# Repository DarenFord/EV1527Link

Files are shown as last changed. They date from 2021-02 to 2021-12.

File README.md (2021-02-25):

# EV1527Link
An EV1527 gateway for use with Domoticz or other home automation systems that support RF Link protocol.

# Download
https://github.com/DarenFord/EV1527Link/releases/latest

# Description
I'm a long-time user of Domoticz and the RF Link gateway (http://www.rflink.nl/blog2/). This is a great combination and works for lots of different home automation products and protocols (like KAKU, X10 and many others). It does, however, not support the EV1527 protocol very well and communication with security products (like door/window sensors, garage door openers, motion sensors, remote controls, etc...) either doesn't work or is unreliable.

I wanted to use cheap security products in my home automation system (like the Kerui D026 door/window sensor, which didn't work correctly/reliably with RF Link) and this led to creating a new gateway specifically for security products that use the EV1527 protocol. The gateway uses RF Link serial protocol to communicate with the home automation system as this protocol is already supported in Domoticz and some other home automation systems.

# Hardware
A Fritzing schematic diagram is included in the package and is extemely simple to wire-up. Build it on an experimental breadboard first to test that it works and, when you're happy, solder the components onto a prototype PCB. If you're feeling really adventurous, you could create a PCB layout and contribute it to the project :-)

It is important to use a good quality receiver module. The receiver module that sometimes comes with the FS-1000A transmitter module is not good enough and I would suggest using an RXB6 module (see parts list below) or something of similar quality.

The parts required to build the gateway:
- 1x Arduino Nano (or other Arduino with a USB port)
- 1x A good 433MHz receiver and ASK transmitter module (e.g. RXB6 receiver and transmitter set https://www.aliexpress.com/item/1005001504888006.html)
- 2x 1K resistor
- 1x Red LED
- 1x Green LED
- 1x Push button for testing

# Installation
Open the .ino file in the repository in the Arduino IDE. Compile and upload the project to your Arduino board.

# Configuration in Domoticz
Go to the hardware section in Domoticz and add a new hardware device with the name "EV1527Link", type "RF Link Gateway USB" and select the gateway's serial/USB port.

If you press the test button, you should see a new device appear in the device section of Domoticz.

I personally use the local (test) button input for the doorbell.

# LAN version
It is possible to connect the gateway directly to the local network and access it from Domoticz. To do this, add a serial to TCP converter (e.g. https://www.aliexpress.com/item/32329316229.html), connected to the TX & RX pins of the Arduino. Don't forget to level-shift the 5 volt TX from the Arduino to the 3 volt RX pin of the serial converter module and add jumpers to your circuit board, so that the converter can be disconnected if and when you need to (re)program the Arduino.

# Contribute to EV1527Link
If you want to contribute: Just create a pull request with your bugfix, addition or anything else you think is valuable.

Something that would be useful is a PCB layout in a format that is supported by PCB manufacturers.

Thanks for your help!

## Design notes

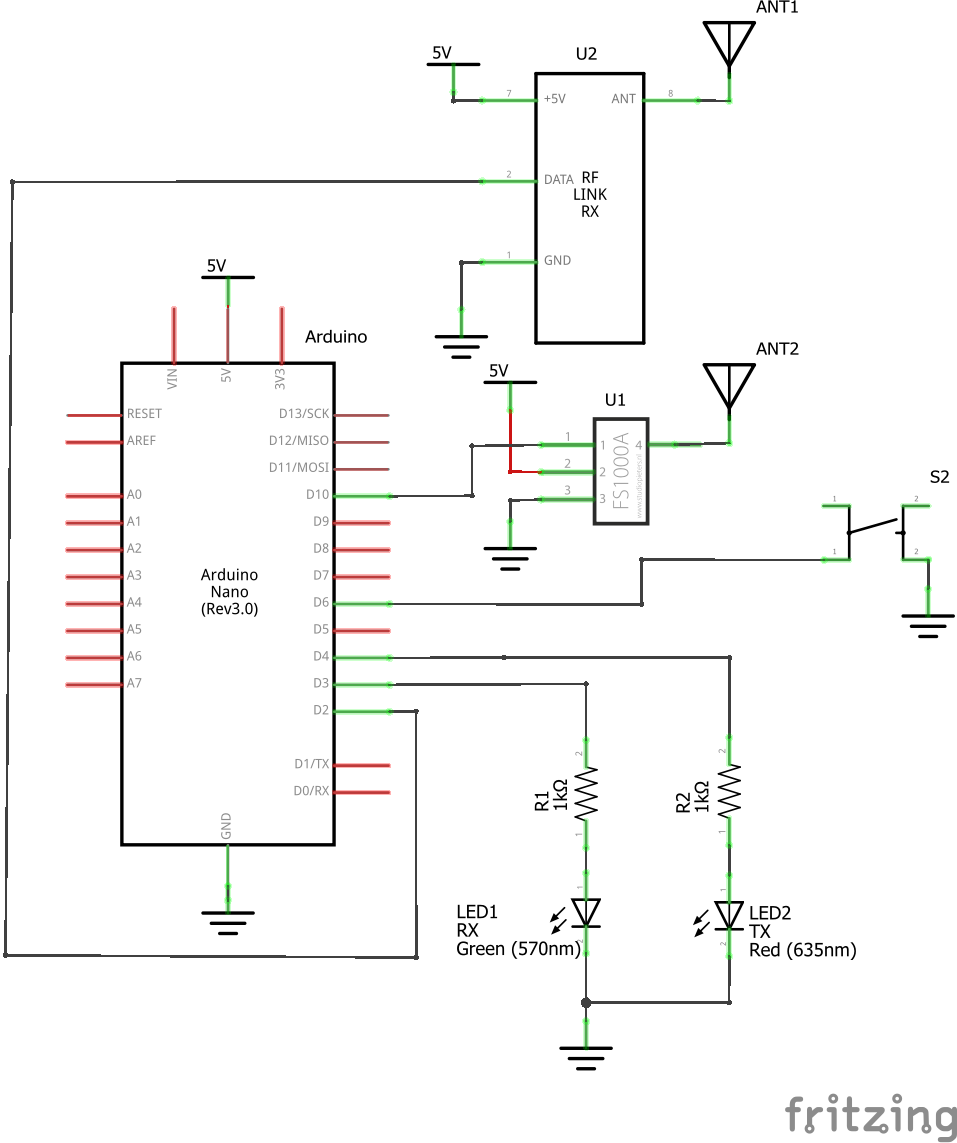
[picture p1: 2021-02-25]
schematic_schem.png

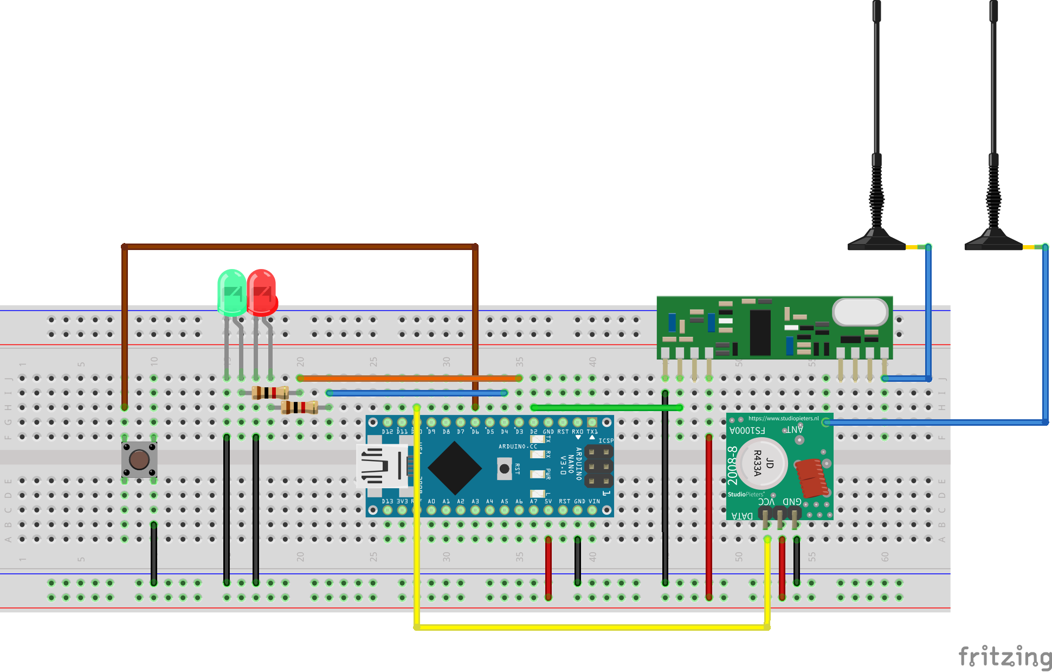
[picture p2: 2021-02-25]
schematic_bb.png

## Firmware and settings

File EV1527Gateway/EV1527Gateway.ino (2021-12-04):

/*
  An EV1527 gateway for use with domoticz and other home automation systems that use the RF Link serial protocol
  Copyright (c) 2020 Daren Ford.  All rights reserved.
    
  Last update: 26/09/2021
  Version: 2.0

  Changes: Added support for Byron protocol (doorbells) - watch out, they use alternating codes (so, two devices will be created)

  Example send command string: 10;Byron;295FD59;03;ON;

  Send commands:
  10;Byron;295FD59;3;ON;

  Loopback commands:
  11;20;45;EV1527;ID=295FD59;SWITCH=3;CMD=ON;
  11;20;45;Byron;ID=295FD59;SWITCH=3;CMD=ON;

  Loopback commands in Domoticz:
  20;45;EV1527;ID=295FD59;SWITCH=3;CMD=ON;
  20;45;Byron;ID=295FD59;SWITCH=3;CMD=ON;

  Project home: https://github.com/DarenFord/EV1527Link
  
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
  This software is distributed in the hope that it will be useful,
  but WITHOUT ANY WARRANTY; without even the implied warranty of
  MERCHANTABILITY or FITNESS FOR A PARTICULAR PURPOSE.  See the GNU
  Lesser General Public License for more details.
  You should have received a copy of the GNU Lesser General Public
  License along with this library; if not, write to the Free Software
  Foundation, Inc., 51 Franklin St, Fifth Floor, Boston, MA  02110-1301  USA  
*/

#include <RCSwitch.h>
#include <Bounce2.h>

//Format for protocol definitions:
//{pulselength, Sync bit, "0" bit, "1" bit}
RCSwitch::Protocol EV1527Protocol = {250, {6, 31}, {1, 3}, {3, 1}, false}; //custom protocol (not in RCSwitch.cpp)
RCSwitch::Protocol ByronProtocol =  {500, {1, 14}, {1, 3}, {3, 1}, false}; //custom protocol (not in RCSwitch.cpp)

RCSwitch rcs = RCSwitch();
String ByronProtocolName = "Byron";
String EV1527ProtocolName = "EV1527";

Bounce debouncer = Bounce();

//version definition
#define VERSION "EV1527 Gateway V2.1"

//input/output pin definitions
#define RX_IRQ 0 // Interrupt number (IRQ 0 = D2) for the 433MHz receiver data pin
#define TX_PIN 10 //433MHz ASK transmitter module (e.g. FS1000A) data pin
#define TX_LED_PIN 4
#define RX_LED_PIN 3
#define INPUT_PIN 6 //digital input - pull down to activate

//communication definitions
#define TX_PULSE_LENGTH 300 //in milliseconds
#define TX_REPEATS 15
#define TX_REPEATS_LEARNING_MODE 50
#define RX_REPEATS 3
#define RX_GUARD_TIME 1000 //in milliseconds
#define RX_LED_DURATION 1000 //in milliseconds

//global variables
int rxCounter = 0;
long lastRxCommand = 0;
int numRxCommands = 0;
uint32_t lastRxCommandReceivedTime = 0;
uint32_t rxLedOnTime = 0;
int lastInputValue = HIGH;

void setup() {
  Serial.begin(57600);
  
  pinMode(TX_LED_PIN, OUTPUT);
  pinMode(RX_LED_PIN, OUTPUT);
  RxLED(LOW);
  TxLED(LOW);

  pinMode(INPUT_PIN, INPUT_PULLUP);
  debouncer.attach(INPUT_PIN);
  debouncer.interval(5);
  
  rcs.enableReceive(RX_IRQ);  
  rcs.enableTransmit(TX_PIN);
  rcs.setPulseLength(TX_PULSE_LENGTH);
  rcs.setRepeatTransmit(TX_REPEATS);  
  SendMessage(VERSION);
}

void loop() {
  if (Serial.available() > 0) {
    String txCommand = Serial.readString();
    ParseTxCommand(txCommand);
  }

  if (rcs.available()) {
    String ProtocolName = "";
    int ProtocolNum = rcs.getReceivedProtocol();
    int BitLength = rcs.getReceivedBitlength();
    int PulseLength = rcs.getReceivedDelay();
    
    if ((ProtocolNum == 1) && (BitLength == 24) && (PulseLength > 230) && (PulseLength < 330)) {
      ProtocolName = EV1527ProtocolName;
    } else if ((ProtocolNum == 2) && (BitLength == 32) && (PulseLength > 680) && (PulseLength < 780)) { //RCSwitch actually reads the pulse length incorrectly ~707mS
      ProtocolName = ByronProtocolName;
    }
    
    if (ProtocolName.length() != 0) {
      long rxCommand = rcs.getReceivedValue();
      uint32_t rxCommandReceivedTime = millis();

      if (rxCommandReceivedTime - lastRxCommandReceivedTime > RX_GUARD_TIME) {
        numRxCommands = 0;
      }
      
      if ((rxCommand == lastRxCommand)  || (lastRxCommand == 0)) {
        numRxCommands++;        
      } else {
        numRxCommands = 0;
      }
      
      if (numRxCommands == RX_REPEATS)
      {
        String rxCommandStr = String(rxCommand, HEX);
        rxCommandStr.toUpperCase();
        String message = ParseRxCommand(rxCommandStr, ProtocolName);
        RxLED(HIGH);
        SendMessage(message);
      }

      lastRxCommand = rxCommand;
      lastRxCommandReceivedTime = rxCommandReceivedTime;
    }
    
    rcs.resetAvailable();    
  }

  if ((rxLedOnTime > 0) && ((millis() - rxLedOnTime) > RX_LED_DURATION)) {
    RxLED(LOW);
  }

  debouncer.update();  
  int value = debouncer.read();  
  if ((value != lastInputValue) && (value == LOW)) {
      EchoCommand(EV1527ProtocolName, "ID=999FF", "SWITCH=01", "CMD=ON");
  }
  lastInputValue = value;
}

void RxOk()
{
  SendMessage("OK");
}

void RxCmdUnknown()
{
  SendMessage("CMD UNKNOWN");
}

void SendMessage(String message)
{  
  String count = String(rxCounter, HEX);
  if (count.length() == 1) {
    count = "0" + count;
  }
  count.toUpperCase();
  
  Serial.print("20;");
  Serial.print(count);
  Serial.print(";");
  Serial.print(message);
  Serial.println(";");

  rxCounter++;
  if (rxCounter > 255) {
    rxCounter = 0;
  }
}

void RxLED(bool state)
{
  if (state == HIGH) {
    rxLedOnTime = millis();
    digitalWrite(RX_LED_PIN, HIGH);
  } else {
    rxLedOnTime = 0;
    digitalWrite(RX_LED_PIN, LOW);
  }
}

void TxLED(bool state)
{
  if (state == HIGH) {
    digitalWrite(TX_LED_PIN, HIGH);
  } else {
    digitalWrite(TX_LED_PIN, LOW);
  }
}

String ParseRxCommand(String rxCommandStr, String ProtocolName)
{
  String toRet = ProtocolName;
  toRet += ";";

  int i = rxCommandStr.length();
  if (i > 0) {
    char device = rxCommandStr[i - 1];
    toRet += "ID=" + rxCommandStr.substring(0, i - 1);
    toRet += ";SWITCH=0";
    toRet += String(device);
    toRet += ";CMD=ON";
  }

  return toRet;
}

void ParseTxCommand(String txCommand) 
{
  //debug code
  //Serial.print("->->");
  //Serial.println(txCommand);

  char cmdProtocol[32] = {0};
  char cmdDevice[16] = {0};
  char cmdUnit[16] = {0};
  char cmdAction[16] = {0};

  char * strtokIdx;
  strtokIdx = strtok(txCommand.c_str(), ";");
  int cmdCode = atoi(strtokIdx);

  switch (cmdCode) {
    case 10: { //transmit code
      strtokIdx = strtok(NULL, ";");
      strcpy(cmdProtocol, strtokIdx);
      String cmdProtocolStr = cmdProtocol;
      if (cmdProtocolStr == "PING") {
        SendMessage("PONG");
        return;          
      } else if (cmdProtocolStr == "VERSION") {
        SendMessage(VERSION);
        return;          
      } else if ((cmdProtocolStr == EV1527ProtocolName) || (cmdProtocolStr == ByronProtocolName)) {
        strtokIdx = strtok(NULL, ";");
        strcpy(cmdDevice, strtokIdx);
        strtokIdx = strtok(NULL, ";");
        strcpy(cmdUnit, strtokIdx);
        strtokIdx = strtok(NULL, ";");
        strcpy(cmdAction, strtokIdx);

        long device = HexToLong((String)cmdDevice);
        long unit = HexToLong((String)cmdUnit);
        if ((device == 0) && (unit == 1)) {
          RxOk();
          ToggleLearningMode(cmdAction);          
          return;          
        } else {
          if (SendCommand(cmdProtocolStr, cmdDevice, cmdUnit, cmdAction)) {
            RxOk();
            return;
          }                  
        }
      }      
      break;
    }
    case 11: { //loopback code
      strtokIdx = strtok(NULL, ";");
      int cmdSubCode = atoi(strtokIdx);
      strtokIdx = strtok(NULL, ";"); //seq nr      
      strtokIdx = strtok(NULL, ";");
      strcpy(cmdProtocol, strtokIdx);
      String cmdProtocolStr = cmdProtocol;
      if ((cmdSubCode == 20) && ((cmdProtocolStr == EV1527ProtocolName) || (cmdProtocolStr == ByronProtocolName))) {
        strtokIdx = strtok(NULL, ";");
        strcpy(cmdDevice, strtokIdx);
        strtokIdx = strtok(NULL, ";");
        strcpy(cmdUnit, strtokIdx);
        strtokIdx = strtok(NULL, ";");
        strcpy(cmdAction, strtokIdx);
        RxOk();
        EchoCommand(cmdProtocolStr, cmdDevice, cmdUnit, cmdAction);
        return;
      }      
      break;
    }
  } 

  RxCmdUnknown();
}

void EchoCommand(String ProtocolName, String cmdDevice, String cmdUnit, String cmdAction)
{
  SendMessage(ProtocolName + ";" + cmdDevice + ";" + cmdUnit + ";" + cmdAction);
}

bool SendCommand(String ProtocolName, String cmdDevice, String cmdUnit, String cmdAction)
{
  cmdAction.toUpperCase();
  if (cmdAction == "ON") {
    if (cmdUnit.startsWith("0") && (cmdUnit.length() == 2)) {
          cmdUnit = cmdUnit.substring(1, 2);
    }
    
    unsigned long code = HexToLong(cmdDevice + cmdUnit);
    TxLED(HIGH);

    if (ProtocolName == EV1527ProtocolName) {
        rcs.setProtocol(EV1527Protocol);
        rcs.send(code, 24);
    } else if (ProtocolName == ByronProtocolName) {
        rcs.setProtocol(ByronProtocol);
        rcs.send(code, 32);
    }
    
    TxLED(LOW);
    return true;
  }

  return false;
}

void ToggleLearningMode(String cmdAction)
{
  if (cmdAction == "ON") {
    rcs.setRepeatTransmit(TX_REPEATS_LEARNING_MODE);
  } else {
    rcs.setRepeatTransmit(TX_REPEATS);
  }
}

unsigned long HexToLong(String str)
{
  unsigned long toRet = 0;
  int len = str.length();
  for (int i = 0; i < len; i++)
  {
    String k = (String)str[i];
    int j = strtol(k.c_str(), 0, 16);
    toRet = toRet * 16;
    toRet += j;
  }
  return toRet;
}

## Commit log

2021-01-02 Added Fritzing schematic diagram
    [schematic.fzz]
2021-01-04 Added local input push-button to schematic diagram
    [schematic.fzz]
2021-01-04 Added .png versions of schematic diagram
2021-02-25 Added an extra antenna
    [schematic.fzz]
2021-02-25 Added extra antenna
2021-03-01 Added learning/training mode (switchable from Domoticz) to train receiver modules (transmits more EV1527 data packages than in normal mode).
